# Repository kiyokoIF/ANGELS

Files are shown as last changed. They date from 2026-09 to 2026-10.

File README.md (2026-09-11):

# ANGELS
A series of sacred musical objects to find god. 

Like Simone Weil and Rilke, I am in search of impossible beauty. For to consume is to destroy. To desire is to enforce infinite separation. Only god can cross this distance. All we can do is wait. These instruments are my prayer, my turning towards god. For there is no heaven or hell, only infinite now.

### ANGEL_001
This angel forces the user to play it with their hands held in prayer. To release pressure is to drop the object, we are forced to hold our attention `en hypomene` like Weil. The goal is to overwhelm the user with options and controls to induce a state of divine inspiration to heighten this feeling of `hypomene`.

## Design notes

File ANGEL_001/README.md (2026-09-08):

# ANGEL_001

## Author

<!-- Insert Your Name Here -->

## Description

<!-- Describe your example here -->

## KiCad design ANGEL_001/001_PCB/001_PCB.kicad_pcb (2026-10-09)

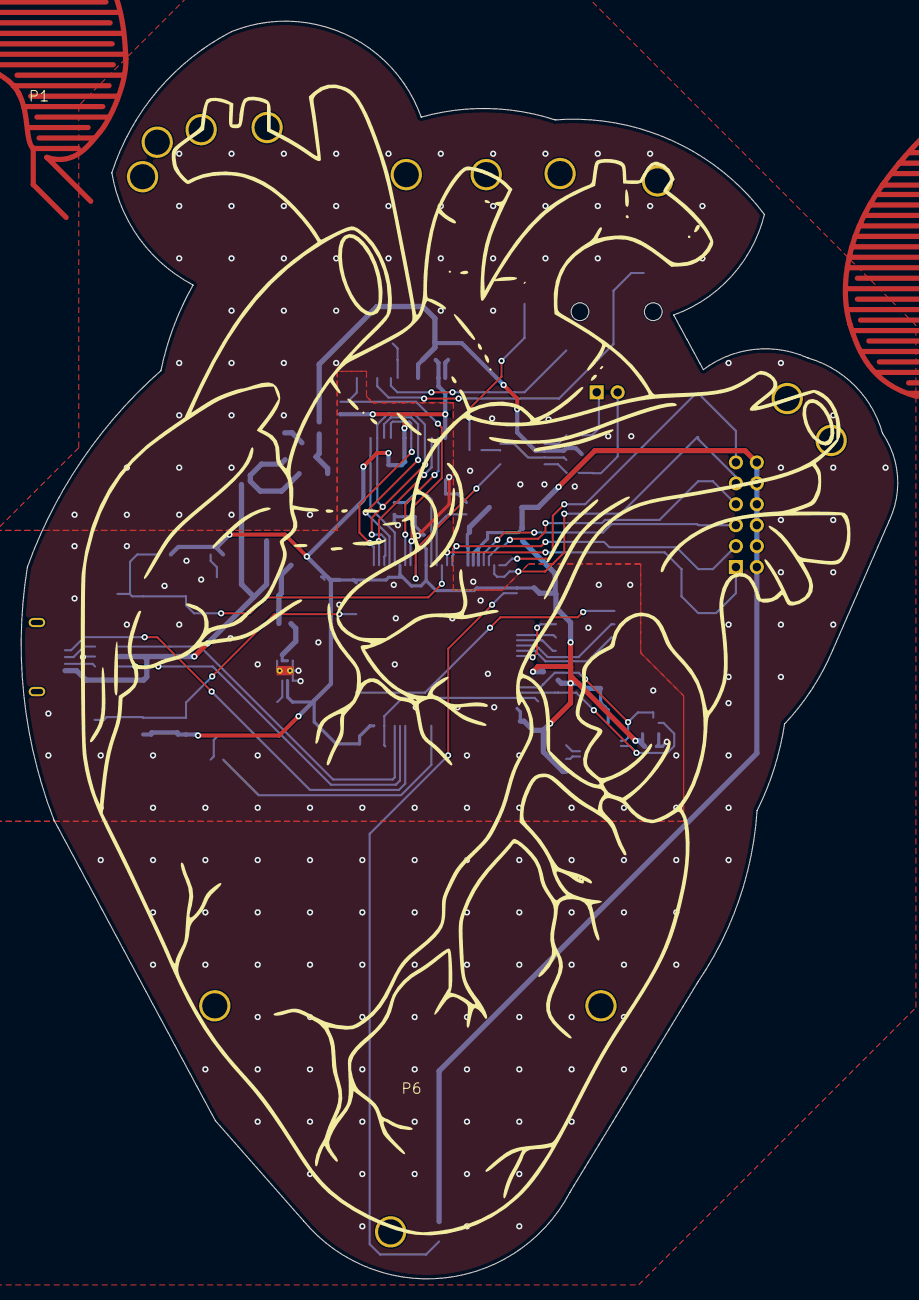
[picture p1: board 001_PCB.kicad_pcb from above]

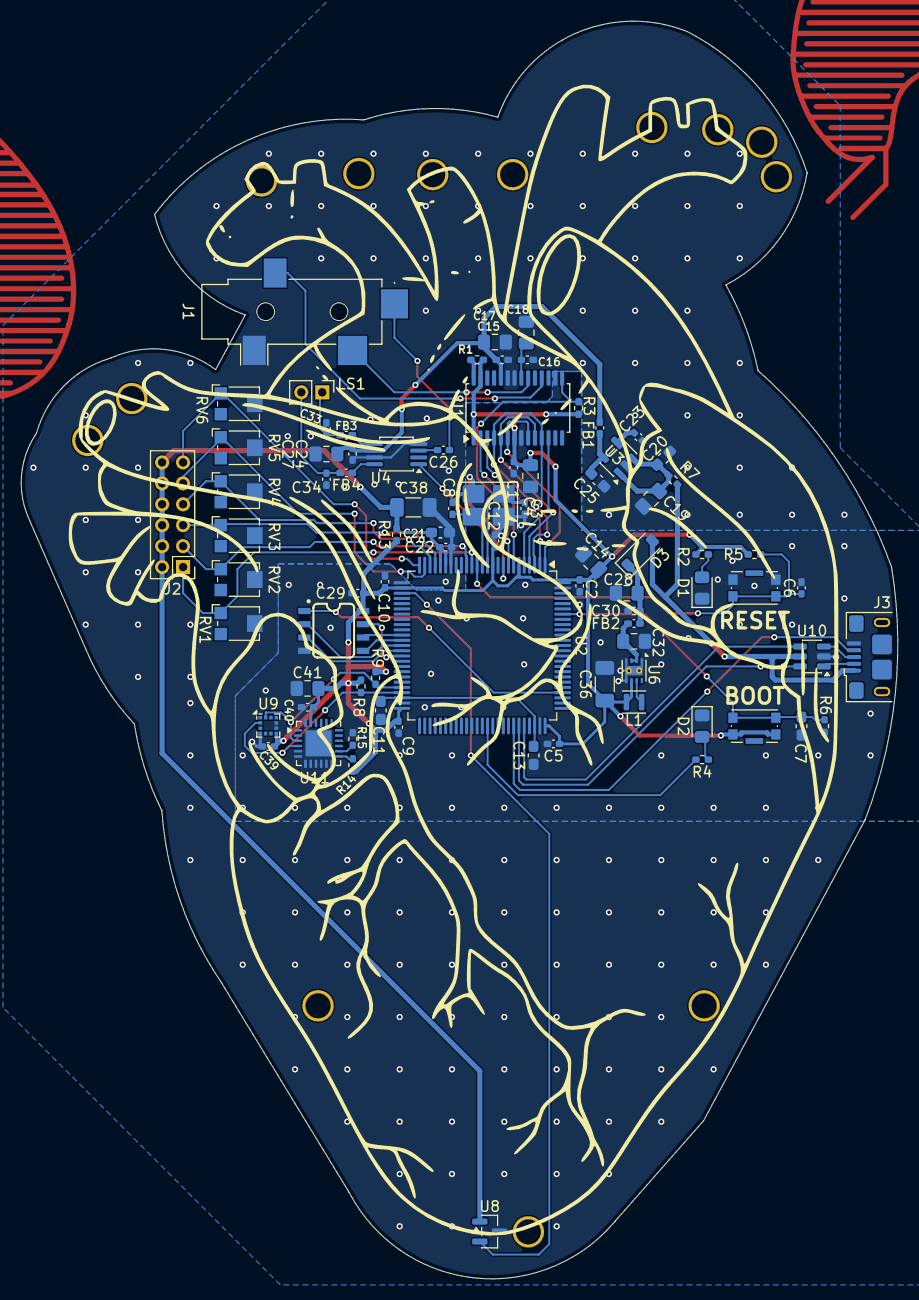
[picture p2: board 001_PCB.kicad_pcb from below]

Board: 2 copper layers, 83.8 x 120.2 mm, 87 parts (81 on the bottom side), 60 nets.

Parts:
C1, C2, C5, C6, C9, C10, C12, C15, C16, C22, C24, C26, C29, C30, C39, C40: 100nF; C_0402_1005Metric_Pad0.74x0.62mm_HandSolder
C3, C8: 12pF; C_0402_1005Metric_Pad0.74x0.62mm_HandSolder
C4, C14, C17, C18, C19, C27, C28, C32, C41: 10uF; C_0805_2012Metric_Pad1.18x1.45mm_HandSolder
C7, C11, C13, C25: 2.2uF; C_0603_1608Metric_Pad1.08x0.95mm_HandSolder
C20, C21: 1uF; C_0603_1608Metric_Pad1.08x0.95mm_HandSolder
C23: 10nF; C_0402_1005Metric_Pad0.74x0.62mm_HandSolder
C33, C34: 220pF; C_0402_1005Metric_Pad0.74x0.62mm_HandSolder
C36, C38: 22uF; C_1206_3216Metric_Pad1.33x1.80mm_HandSolder
D1: PWR_LED; LED_0805_2012Metric_Pad1.15x1.40mm_HandSolder
D2: USER_LED; LED_0805_2012Metric_Pad1.15x1.40mm_HandSolder
D3: D; D_SOD-123
FB1, FB2, FB3, FB4: FerriteBead_Small; L_0402_1005Metric_Pad0.77x0.64mm_HandSolder
J1: AudioJack3_SwitchT; Jack_3.5mm_CUI_SJ-3524-SMT_Horizontal
J2: Conn_02x06_Odd_Even; PinHeader_2x06_P2.00mm_Vertical
J3: USB_B_Micro; USB_Micro-B_Amphenol_10118193-0001LF_Horizontal
L1: 2.2uH; L_Murata_DFE201610P
LS1: Speaker; PinHeader_1x02_P2.00mm_Vertical
P1: FSR_Pinky
P2: FSR_Ring
P3: FSR_Middle
P4: FSR_Index
P5: FSR_Thumb
P6: FSR_Palm
R1: 220k; R_0402_1005Metric_Pad0.72x0.64mm_HandSolder
R2, R4: 1k; R_0402_1005Metric_Pad0.72x0.64mm_HandSolder
R3, R5, R8, R9, R14: 10k; R_0402_1005Metric_Pad0.72x0.64mm_HandSolder
R6: 47k; R_0402_1005Metric_Pad0.72x0.64mm_HandSolder
R7, R13: 5R1; R_0402_1005Metric_Pad0.72x0.64mm_HandSolder
R15: 150k; R_0402_1005Metric_Pad0.72x0.64mm_HandSolder
RV1, RV2, RV3, RV4, RV5, RV6: 50k Trim; Potentiometer_Bourns_TC33X_Vertical
SW1, SW2: SW_Push_1P1T-SH_NO_CK_KMR2xxG
U1: PCM3060; TSSOP-28_4.4x9.7mm_P0.65mm
U2: STM32H750VBTx; LQFP-100_14x14mm_P0.5mm
U3: LP2985-5.0; SOT-23-5
U4: PAM8302AAS; MSOP-8_3x3mm_P0.65mm
U5: IS25LP032D-JNLE; SO-8
U6: TPS62172DSG; WSON-8-1EP_2x2mm_P0.5mm_EP0.9x1.6mm_ThermalVias
U8: MCP9700x-HTT; SOT-23
U9: MSA311; LGA-12_2x2mm_P0.5mm
U10: USBLC6-2SC6; SOT-23-6
U11: CAP1188; QFN-24-1EP_4x4mm_P0.5mm_EP2.5x2.5mm
Y1: 16MHz; Crystal_SMD_SeikoEpson_TSX3225-4Pin_3.2x2.5mm_HandSoldering

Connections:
+3.3V: C1.1, C2.1, C4.1, C5.1, C9.1, C10.1, C12.1, C14.1, C29.1, C36.1, C39.1, C40.1, C41.1, L1.2, R1.1, R2.1, R3.1, R5.1, R8.1, R9.1, R13.1, R14.1, SW2.1 (A), U1.1 (MC/SCL/FMT), U1.7 (V_{DD}), U1.27 (~MS/AD/IFMD), U2.6 (VBAT), U2.11 (VDD), U2.27 (VDD), U2.50 (VDD), U2.75 (VDD), U2.100 (VDD), U5.8 (VCC), U6.6 (VOS), U9.7 (VDD), U11.23 (VDD)
+3.3VA: C21.1, C22.1, C38.1, J2.2, J2.4, J2.6, J2.8, J2.10, J2.12, R13.2, U2.20 (VREF+), U2.21 (VDDA), U8.1 (V_{DD})
+5V: C15.1, C17.1, C24.1, C27.1, FB1.2, U1.24 (V_{CC}), U4.6 (VDD)
/AMP_SD: U2.9 (PC15), U4.1 (~SD)
/AUDIO_L: J1.T, U1.20 (V_{OUT}L+)
/AUDIO_L_SP: C26.1, J1.TN
/AUDIO_R: J1.R, U1.18 (V_{OUT}R+)
/BOOT: C7.1, R6.1, SW2.2 (B), U2.94 (BOOT0)
/CODEC_DEMP: U1.2 (MD/SDA/DEMP), U2.7 (PC13)
/CODEC_RST: R3.2, U1.15 (~RST), U2.8 (PC14)
/FSR_1: J2.1, RV1.1, U2.15 (ADC1_INP10)
/FSR_2: J2.3, RV2.1, U2.16 (ADC1_INP11)
/FSR_3: J2.5, RV3.1, U2.22 (ADC1_INP16)
/FSR_4: J2.7, RV4.1, U2.23 (ADC1_INP17)
/FSR_5: J2.9, RV5.1, U2.24 (ADC1_INP14)
/FSR_6: J2.11, RV6.1, U2.25 (ADC1_INP15)
/I2C1_SCL: R8.2, U2.47 (I2C2_SDA), U9.2 (SDA), U11.4 (SCL/SPI_CLK)
/I2C1_SDA: R9.2, U2.46 (I2C2_SCL), U9.12 (SCL), U11.3 (SDA/SPI_MISO)
/OSC_IN: C3.2, U2.12 (RCC_OSC_IN), Y1.1
/OSC_OUT: C8.2, U2.13 (RCC_OSC_OUT), Y1.3
/QSPI_CLK: U2.36 (QUADSPI_CLK), U5.6 (CLK)
/QSPI_IO0: U2.37 (QUADSPI_BK2_IO0), U5.5 (D0/DI)
/QSPI_IO1: U2.38 (QUADSPI_BK2_IO1), U5.2 (D1/DO)
/QSPI_IO2: U2.39 (QUADSPI_BK2_IO2), U5.3 (D2/~WP)
/QSPI_IO3: U2.40 (QUADSPI_BK2_IO3), U5.7 (D3/~HOLD)
/QSPI_NCS: U2.79 (QUADSPI_BK2_NCS), U5.1 (~CS)
/RESET: C6.1, R5.2, SW1.2 (B), U2.14 (NRST)
/SAI1_FS: U1.4 (LRCK1), U1.11 (LRCK2), U2.3 (SAI1_FS_A)
/SAI1_MCLK: U1.6 (SCKI1), U1.9 (SCKI2), U2.1 (SAI1_MCLK_A)
/SAI1_SCK: U1.5 (BCK1), U1.10 (BCK2), U2.4 (SAI1_SCK_A)
/SAI1_SD_A: U1.12 (DIN), U2.5 (SAI1_SD_A)
/SAI1_SD_B: U1.3 (DOUT), U2.2 (SAI1_SD_B)
/TEMP_SENS: U2.28 (ADC1_INP18), U8.2 (V_{OUT})
/USB_DM: U2.70 (USB_OTG_FS_DM), U10.6 (I/O1)
/USB_DM_IN: J3.2 (D-), U10.1 (I/O1)
/USB_DP: U2.71 (USB_OTG_FS_DP), U10.4 (I/O2)
/USB_DP_IN: J3.3 (D+), U10.3 (I/O2)
/USB_ID: J3.4 (ID), U2.69 (USB_OTG_FS_ID)
/USER_LED: R4.1, U2.64 (PC7)
GNDA: C15.2, C16.2, C17.2, C18.2, C19.2, C20.2, C21.2, C22.2, C23.2, C24.2, C25.2, C27.2, C33.2, C34.2, C38.2, J1.S, RV1.2, RV2.2, RV3.2, RV4.2, RV5.2, RV6.2, U1.22 (AGND2), U1.23 (AGND1), U2.19 (VSSA), U3.2 (GND), U4.4 (IN-), U4.7 (GND), U8.3 (GND)
GNDD: C1.2, C2.2, C3.1, C4.2, C5.2, C6.2, C7.2, C8.1, C9.2, C10.2, C11.2, C12.2, C13.2, C14.2, C28.2, C29.2, C30.2, C32.2, C36.2, C39.2, C40.2, C41.2, D1.1 (K), D2.1 (K), J3.5 (GND), R6.2, R15.2, SW1.1 (A), U1.8 (DGND), U1.16 (SGND), U2.10 (VSS), U2.26 (VSS), U2.49 (VSS), U2.74 (VSS), U2.99 (VSS), U5.4 (GND), U6.1 (PGND), U6.4 (AGND), U6.5 (FB), U6.9 (PAD), U9.4 (GND), U9.8 (GND), U9.9 (GND), U10.2 (GND), U11.5 (LED1), U11.6 (LED2), U11.7 (LED3), U11.8 (LED4), U11.9 (LED5), U11.10 (LED6), U11.11 (LED7), U11.12 (LED8), U11.24 (RESET), U11.25 (GND), Y1.2 (G), Y1.4 (G)
unnamed: C11.1, C13.1, U2.48 (VCAP), U2.73 (VCAP)
unnamed: C33.1, FB3.2, LS1.1
unnamed: C34.1, FB4.2, LS1.2
unnamed: D1.2 (A), R2.2
unnamed: D2.2 (A), R4.2
unnamed: C28.1, C30.1, D3.1 (K), FB2.1
unnamed: R1.2, U1.28 (MODE)
unnamed: C16.1, C18.1, U1.21 (V_{COM})
unnamed: C23.1, U3.4 (BP)
unnamed: C19.1, C20.1, R7.2, U3.1 (VIN), U3.3 (ON/~OFF)
unnamed: C25.1, FB1.1, U3.5 (VOUT)
unnamed: C26.2, U4.3 (IN+)
unnamed: FB3.1, U4.5 (OUT+)
unnamed: FB4.1, U4.8 (OUT-)
unnamed: C32.1, FB2.2, U6.2 (VIN), U6.3 (EN)
unnamed: L1.1, U6.7 (SW)
unnamed: R15.1, U11.14 (ADDR_COMM)
unnamed: R14.2, U11.13 (ALERT#)
VIN: D3.2 (A), J3.1 (VBUS), R7.1, U10.5 (VBUS)

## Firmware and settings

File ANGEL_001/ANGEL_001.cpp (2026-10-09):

#include "daisy_seed.h"
#include "daisysp.h"
#include "periph/msa311.h"
#include "periph/cap1188.h"
#include "periph/sgtl5000.h"

#define ADC_CHANNELS 	6	// number of ADC Channels needed 

#define BYTE_TO_BINARY_PATTERN "%c%c%c%c%c%c%c%c"
#define BYTE_TO_BINARY(byte)  \
  ((byte) & 0x80 ? '#' : '.'), \
  ((byte) & 0x40 ? '#' : '.'), \
  ((byte) & 0x20 ? '#' : '.'), \
  ((byte) & 0x10 ? '#' : '.'), \
  ((byte) & 0x08 ? '#' : '.'), \
  ((byte) & 0x04 ? '#' : '.'), \
  ((byte) & 0x02 ? '#' : '.'), \
  ((byte) & 0x01 ? '#' : '.') 

using namespace daisy;
using namespace daisysp;

DaisySeed hw;

MSA311 *accel;

CAP1188 *cap;

I2CHandle i2c;
SaiHandle sai_2_handle_;

Oscillator osc;

void AudioCallback(AudioHandle::InputBuffer in, AudioHandle::OutputBuffer out, size_t size)
{
	for (size_t i = 0; i < size; i++)
	{
		float sig = osc.Process();
		out[0][i] = sig;
		out[1][i] = sig;
	}
}

int main(void)
{
	hw.Init();

	// // Adding secondary SAI i2s output
	// SaiHandle::Config sai2Config;
	// sai2Config.periph          = SaiHandle::Config::Peripheral::SAI_2;
    // sai2Config.sr              = SaiHandle::Config::SampleRate::SAI_8KHZ;
    // sai2Config.bit_depth       = SaiHandle::Config::BitDepth::SAI_16BIT;
    // sai2Config.a_sync          = SaiHandle::Config::Sync::SLAVE;
    // sai2Config.b_sync          = SaiHandle::Config::Sync::MASTER;
    // sai2Config.a_dir           = SaiHandle::Config::Direction::TRANSMIT;
    // sai2Config.b_dir           = SaiHandle::Config::Direction::TRANSMIT;
    // sai2Config.pin_config.fs   = seed::D27;
    // sai2Config.pin_config.mclk = seed::D24;
    // sai2Config.pin_config.sck  = seed::D28;
    // sai2Config.pin_config.sb   = seed::D25;
    // sai2Config.pin_config.sa   = seed::D26;

	// sai_2_handle_.Init(sai2Config);

	// // Setting Audio to work with i2s out
    // AudioHandle::Config audio_config;
    // audio_config.blocksize  = 64;
    // audio_config.samplerate = SaiHandle::Config::SampleRate::SAI_8KHZ;
    // audio_config.postgain   = 1.f;

	// // hw.audio_handle.DeInit(); // will deinit sai1 as well which is bad. I don't think reinitializing is bad
    // hw.audio_handle.Init(audio_config, hw.AudioSaiHandle(), sai_2_handle_);

	hw.SetAudioBlockSize(4);
	hw.SetAudioSampleRate(SaiHandle::Config::SampleRate::SAI_48KHZ);

	osc.Init(hw.AudioSampleRate());
	osc.SetFreq(50);
	osc.SetAmp(1);
	osc.SetWaveform(osc.WAVE_SIN); 

	// Setting up ADCs
	AdcChannelConfig adc_config[ADC_CHANNELS];
	
	adc_config[0].InitSingle(seed::A0);
	adc_config[1].InitSingle(seed::A1);
	adc_config[2].InitSingle(seed::A2);
	adc_config[3].InitSingle(seed::A3);
	adc_config[4].InitSingle(seed::A4);
	adc_config[5].InitSingle(seed::A5);

	// Initialize the ADC peripheral with that configuration
	hw.adc.Init(adc_config, ADC_CHANNELS);

	// Start the ADC
	hw.adc.Start();	

	// Serial Output
	hw.StartLog();
	System::Delay(500);
	hw.PrintLine("Serial Out Working. SAI1: %d SAI2: %d", hw.AudioSaiHandle().IsInitialized(), sai_2_handle_.IsInitialized());

	// Setting up I2C comms for peripherals
	I2CHandle::Config i2c_conf;

	i2c_conf.periph 		= I2CHandle::Config::Peripheral::I2C_1;
    i2c_conf.speed 			= I2CHandle::Config::Speed::I2C_400KHZ;
    i2c_conf.mode 			= I2CHandle::Config::Mode::I2C_MASTER;
    i2c_conf.pin_config.scl = seed::D11;
    i2c_conf.pin_config.sda = seed::D12;

    i2c.Init(i2c_conf);

	System::Delay(500);

	accel = new MSA311();

	if (!accel->Init(&i2c)) {
		hw.PrintLine("MSA311 not found");
		while(1){}
	} else {
		hw.PrintLine("MSA311 found");
	}

	System::Delay(500);

	cap = new CAP1188(); 

	if (!cap->Init(&i2c)) {
		hw.PrintLine("CAP1188 not found");
		while(1){}
	} else {
		hw.PrintLine("CAP1188 found");
	}

	System::Delay(500);

	// Start Audio
	hw.StartAudio(AudioCallback);
	
	while(1) {

		for (int i = 0; i < ADC_CHANNELS; i++) {
			int value = hw.adc.Get(i);

			float percent = (float) value / 65536.0f;

			hw.Print("ADC%d: %.3f  ", i, percent);
		}

		accel->Update();
		cap->Update();

		hw.PrintLine("X: %5d, Y: %5d, Z:%5d, CAP:" BYTE_TO_BINARY_PATTERN, accel->getX(), accel->getY(), accel->getZ(), BYTE_TO_BINARY(cap->getSens()));

		System::Delay(100);
	}
}

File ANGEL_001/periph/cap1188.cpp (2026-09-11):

#include "cap1188.h"

bool CAP1188::Init(I2CHandle *_i2c) {
    i2c = _i2c;

    Read(CAP1188_PRODID, 1);
    if (buf[0] != 0x50) return false;

    Read(CAP1188_MANUID, 1);
    if (buf[0] != 0x5D) return false;

    buf[0] = CAP1188_MTBLK;
    buf[1] = 0x00;
    i2c->TransmitBlocking(CAP1188_I2CADDR, buf, 2, TIMEOUT);

    buf[0] = CAP1188_LEDLINK;
    buf[1] = 0x00;
    i2c->TransmitBlocking(CAP1188_I2CADDR, buf, 2, TIMEOUT);

    buf[0] = CAP1188_MAIN;
    buf[1] = 0x00 | (GAIN << 6);
    i2c->TransmitBlocking(CAP1188_I2CADDR, buf, 2, TIMEOUT);

    buf[0] = CAP1188_INT_EN;
    buf[1] = 0xFF;
    i2c->TransmitBlocking(CAP1188_I2CADDR, buf, 2, TIMEOUT);

    buf[0] = CAP1188_STANDBYCFG;
    buf[1] = 0xFF;
    i2c->TransmitBlocking(CAP1188_I2CADDR, buf, 2, TIMEOUT);

    return true;
}

void CAP1188::Read(uint16_t REG, uint16_t size) {
    buf[0] = REG;
    i2c->TransmitBlocking(CAP1188_I2CADDR, buf, 1, TIMEOUT);
    i2c->ReceiveBlocking(CAP1188_I2CADDR, buf, size, TIMEOUT);
}

void CAP1188::Update() {
    Read(CAP1188_SENINPUTSTATUS, 1);
    sens = buf[0];
    // resetting interupt bit
    if (sens) {
        buf[0] = CAP1188_MAIN;
        buf[1] = 0x00 | (GAIN << 6);
        i2c->TransmitBlocking(CAP1188_I2CADDR, buf, 2, TIMEOUT);
    }
}

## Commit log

2026-09-08 removing directories
    [Daisy_Seed_Rev4_Pinout.csv]
2026-09-11 Added capacitive touch IC + Testing SAI2 with SGTL5000
2026-09-22 Beginning PCB Design
    [001_PCB.kicad_pcb, 001_PCB.kicad_sch]
2026-10-05 PCB work + speaker testing
    [001_PCB.kicad_pcb, 001_PCB.kicad_sch]
2026-10-09 PCB finalization + FSR design
    [001_PCB.kicad_pcb, 001_PCB.kicad_sch]
2026-11-01 modifying for new board
